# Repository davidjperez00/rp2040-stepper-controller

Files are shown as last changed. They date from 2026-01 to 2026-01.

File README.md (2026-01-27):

# rp2040-stepper-controller
This project utilizes the RP2040 microcontroller and A4988 motor drivers on a custom PCB to control NEMA-17 stepper motors. This PCB is equipped with four A4988 providing the ability to drive multiple motors from a single microntroller. Headers pins provide the ability of micro-stepping for each motor. The micro-USB allows for easy flashing from a host machine. The 32MB of external flash memory provide the ability to flash large programs.

## Demo (Click Thumbnail to see Youtube video)
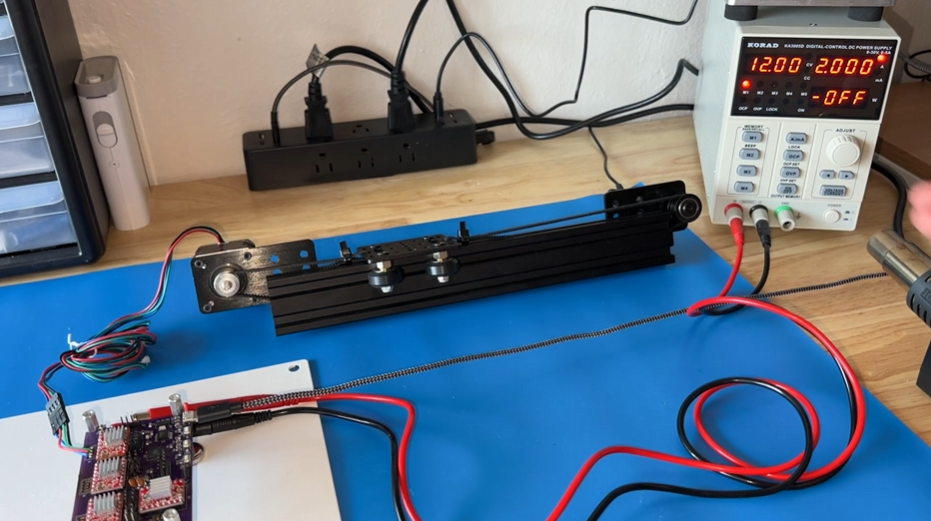
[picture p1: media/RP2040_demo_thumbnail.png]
Video Demo Thumbnail (https://www.youtube.com/watch?v=CGf28lo1xpw)


## PCB Snapshots
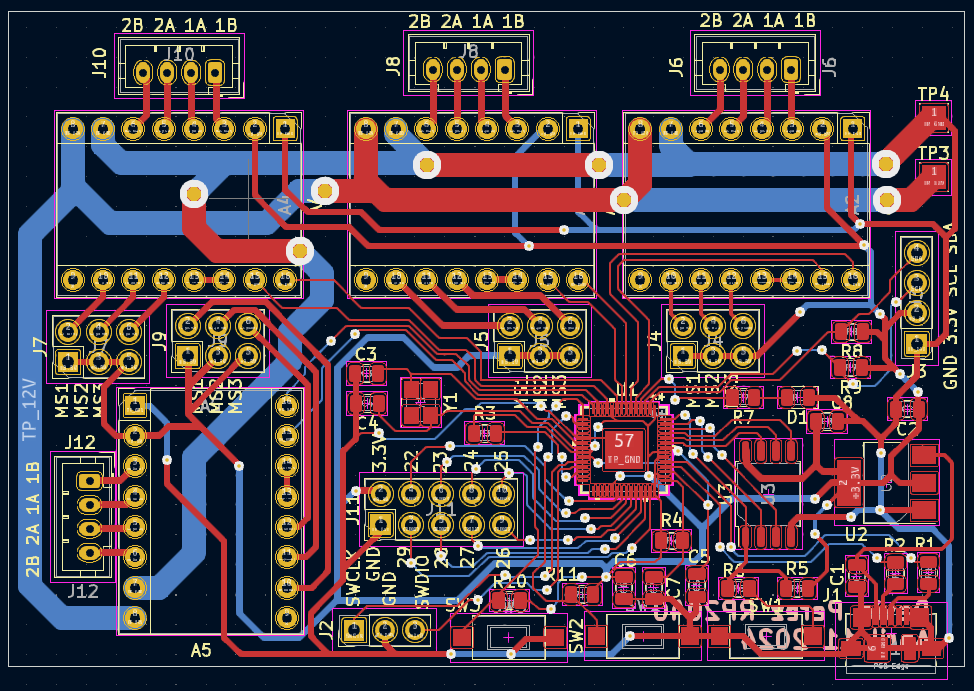
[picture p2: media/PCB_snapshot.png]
PCB snapshot


## Schematic Snapshots
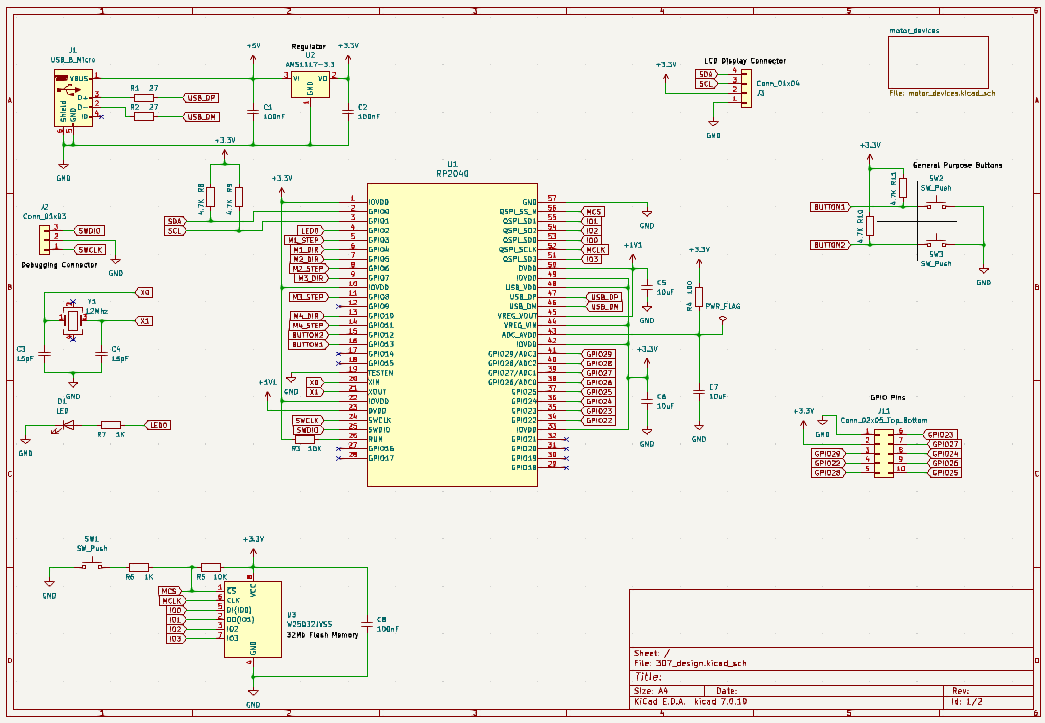
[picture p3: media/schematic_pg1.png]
Schematic Page 1

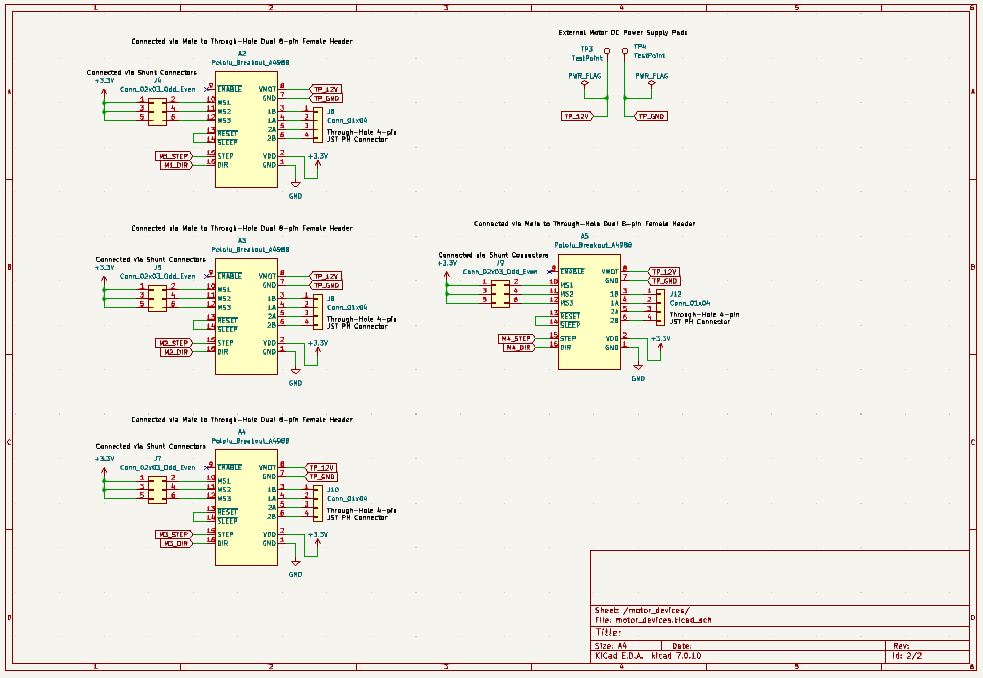
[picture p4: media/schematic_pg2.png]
Schematic Page 2


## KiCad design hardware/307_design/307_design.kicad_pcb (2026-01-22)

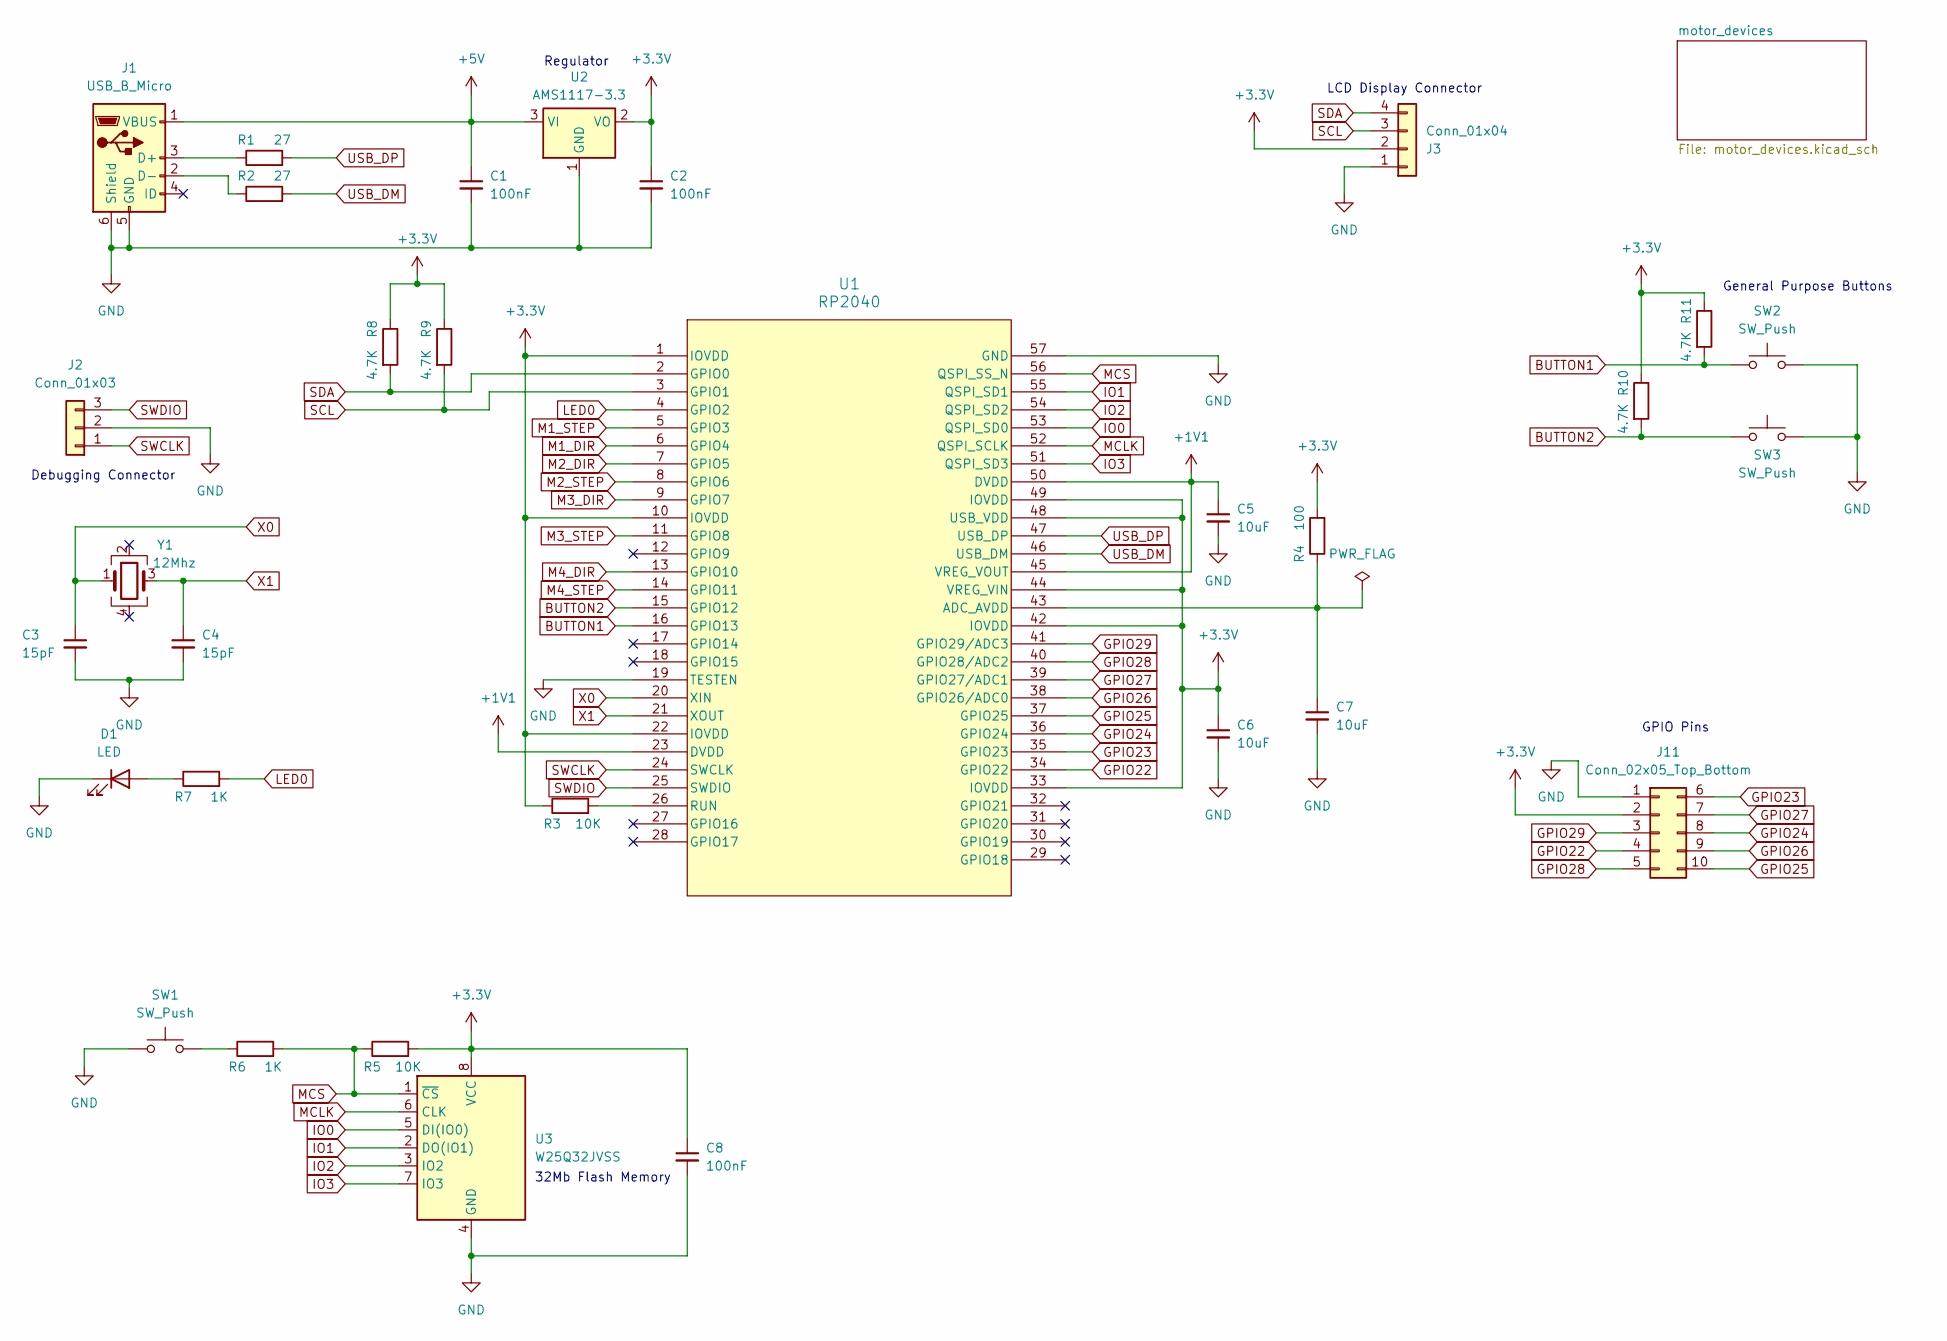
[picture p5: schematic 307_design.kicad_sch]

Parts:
C1, C2, C8: 100nF; C_0805_2012Metric
C3, C4: 15pF; C_0805_2012Metric
C5, C6, C7: 10uF; C_0805_2012Metric
D1: LED; LED_0805_2012Metric
J1: USB_B_Micro; USB_Micro-B_Molex_47346-0001
J2: Conn_01x03; PinHeader_1x03_P2.54mm_Vertical
J3: Conn_01x04; PinHeader_1x04_P2.54mm_Vertical
J11: Conn_02x05_Top_Bottom; PinHeader_2x05_P2.54mm_Vertical
R1, R2: 27; R_0805_2012Metric
R3, R5: 10K; R_0805_2012Metric
R4: 100; R_0805_2012Metric
R6, R7: 1K; R_0805_2012Metric
R8, R9, R10, R11: 4.7K; R_0805_2012Metric
SW1, SW2, SW3: SW_Push; SW_SPST_CK_RS282G05A3
U1: RP2040; IC57_RP2040
U2: AMS1117-3.3; SOT-223-3_TabPin2
U3: W25Q32JVSS; SOIC-8_5.23x5.23mm_P1.27mm
Y1: 12Mhz; Crystal_SMD_SeikoEpson_FA238-4Pin_3.2x2.5mm

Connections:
+1V1: C5.1, U1.23 (DVDD), U1.45 (VREG_VOUT), U1.50 (DVDD)
+3.3V: C2.1, C6.1, C8.1, J3.2, J11.2, R3.1, R4.2, R5.2, R8.1, R9.1, R10.1, R11.1, U1.1 (IOVDD), U1.10 (IOVDD), U1.22 (IOVDD), U1.33 (IOVDD), U1.42 (IOVDD), U1.44 (VREG_VIN), U1.48 (USB_VDD), U1.49 (IOVDD), U2.2 (VO), U3.8 (VCC); also elsewhere on the board
+5V: C1.1, J1.1 (VBUS), U2.3 (VI)
BUTTON1: R11.2, SW2.1, U1.16 (GPIO13)
BUTTON2: R10.2, SW3.1, U1.15 (GPIO12)
GPIO22: J11.4, U1.34 (GPIO22)
GPIO23: J11.6, U1.35 (GPIO23)
GPIO24: J11.8, U1.36 (GPIO24)
GPIO25: J11.10, U1.37 (GPIO25)
GPIO26: J11.9, U1.38 (GPIO26/ADC0)
GPIO27: J11.7, U1.39 (GPIO27/ADC1)
GPIO28: J11.5, U1.40 (GPIO28/ADC2)
GPIO29: J11.3, U1.41 (GPIO29/ADC3)
IO0: U1.53 (QSPI_SD0), U3.5 (DI(IO0))
IO1: U1.55 (QSPI_SD1), U3.2 (DO(IO1))
IO2: U1.54 (QSPI_SD2), U3.3 (IO2)
IO3: U1.51 (QSPI_SD3), U3.7 (IO3)
LED0: R7.2, U1.4 (GPIO2)
M1_DIR: U1.6 (GPIO4); also elsewhere on the board
M1_STEP: U1.5 (GPIO3); also elsewhere on the board
M2_DIR: U1.7 (GPIO5); also elsewhere on the board
M2_STEP: U1.8 (GPIO6); also elsewhere on the board
M3_DIR: U1.9 (GPIO7); also elsewhere on the board
M3_STEP: U1.11 (GPIO8); also elsewhere on the board
M4_DIR: U1.13 (GPIO10); also elsewhere on the board
M4_STEP: U1.14 (GPIO11); also elsewhere on the board
MCLK: U1.52 (QSPI_SCLK), U3.6 (CLK)
MCS: R5.1, R6.2, U1.56 (QSPI_SS_N), U3.1 (~CS)
unnamed: D1.2 (A), R7.1
unnamed: J1.3 (D+), R1.1
unnamed: J1.2 (D-), R2.1
unnamed: R6.1, SW1.2
unnamed: C7.1, R4.1, U1.43 (ADC_AVDD)
unnamed: R3.2, U1.26 (RUN)
SCL: J3.3, R9.2, U1.3 (GPIO1)
SDA: J3.4, R8.2, U1.2 (GPIO0)
SWCLK: J2.1, U1.24 (SWCLK)
SWDIO: J2.3, U1.25 (SWDIO)
USB_DM: R2.2, U1.46 (USB_DM)
USB_DP: R1.2, U1.47 (USB_DP)
X0: C3.1, U1.20 (XIN), Y1.1
X1: C4.1, U1.21 (XOUT), Y1.3

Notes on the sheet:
General Purpose Buttons
Debugging Connector
GPIO Pins
LCD Display Connector
Regulator
32Mb Flash Memory

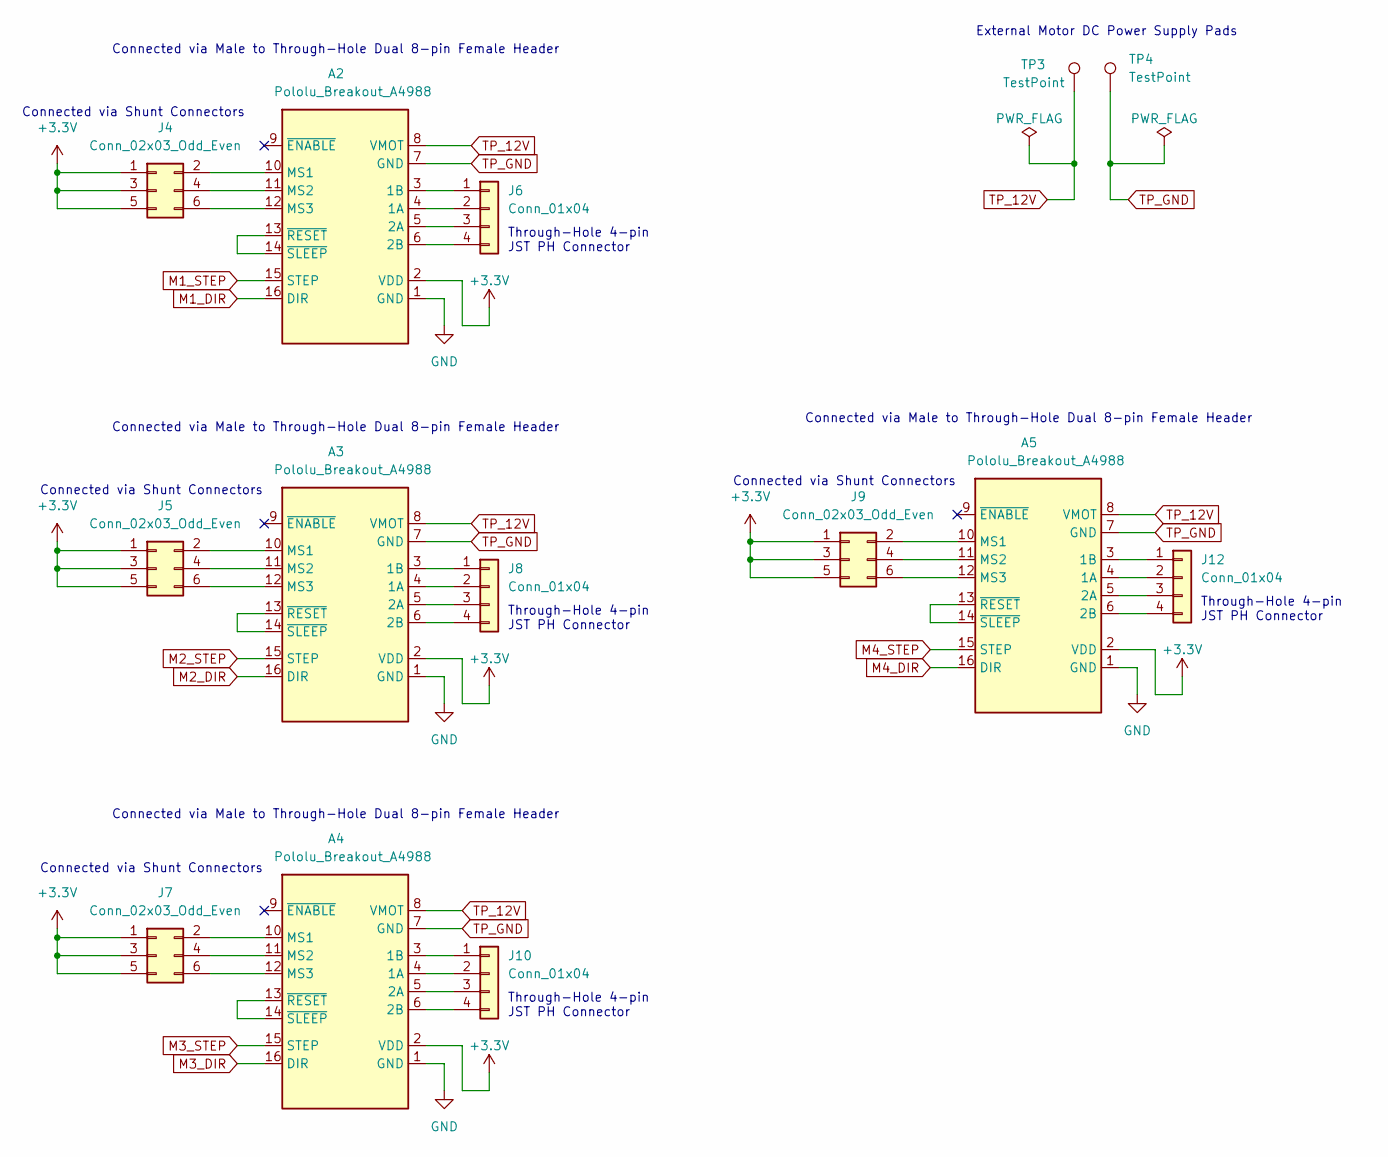
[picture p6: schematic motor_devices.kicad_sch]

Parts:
A2, A3, A4, A5: Pololu_Breakout_A4988; Pololu_Breakout-16_15.2x20.3mm
J4, J5, J7, J9: Conn_02x03_Odd_Even; PinHeader_2x03_P2.54mm_Vertical
J6, J8, J10, J12: Conn_01x04; JST_PH_B4B-PH-K_1x04_P2.00mm_Vertical
TP3, TP4: TestPoint; TestPoint_Pad_2.0x2.0mm

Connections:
+3.3V: A2.2 (VDD), A3.2 (VDD), A4.2 (VDD), A5.2 (VDD), J4.1, J4.3, J4.5, J5.1, J5.3, J5.5, J7.1, J7.3, J7.5, J9.1, J9.3, J9.5; also elsewhere on the board
M1_DIR: A2.16 (DIR); also elsewhere on the board
M1_STEP: A2.15 (STEP); also elsewhere on the board
M2_DIR: A3.16 (DIR); also elsewhere on the board
M2_STEP: A3.15 (STEP); also elsewhere on the board
M3_DIR: A4.16 (DIR); also elsewhere on the board
M3_STEP: A4.15 (STEP); also elsewhere on the board
M4_DIR: A5.16 (DIR); also elsewhere on the board
M4_STEP: A5.15 (STEP); also elsewhere on the board
unnamed: A2.4 (1A), J6.2
unnamed: A2.3 (1B), J6.1
unnamed: A2.5 (2A), J6.3
unnamed: A2.6 (2B), J6.4
unnamed: A2.10 (MS1), J4.2
unnamed: A2.11 (MS2), J4.4
unnamed: A2.12 (MS3), J4.6
unnamed: A2.13 (~RESET), A2.14 (~SLEEP)
unnamed: A3.4 (1A), J8.2
unnamed: A3.3 (1B), J8.1
unnamed: A3.5 (2A), J8.3
unnamed: A3.6 (2B), J8.4
unnamed: A3.10 (MS1), J5.2
unnamed: A3.11 (MS2), J5.4
unnamed: A3.12 (MS3), J5.6
unnamed: A3.13 (~RESET), A3.14 (~SLEEP)
unnamed: A4.4 (1A), J10.2
unnamed: A4.3 (1B), J10.1
unnamed: A4.5 (2A), J10.3
unnamed: A4.6 (2B), J10.4
unnamed: A4.10 (MS1), J7.2
unnamed: A4.11 (MS2), J7.4
unnamed: A4.12 (MS3), J7.6
unnamed: A4.13 (~RESET), A4.14 (~SLEEP)
unnamed: A5.4 (1A), J12.2
unnamed: A5.3 (1B), J12.1
unnamed: A5.5 (2A), J12.3
unnamed: A5.6 (2B), J12.4
unnamed: A5.10 (MS1), J9.2
unnamed: A5.11 (MS2), J9.4
unnamed: A5.12 (MS3), J9.6
unnamed: A5.13 (~RESET), A5.14 (~SLEEP)
TP_12V: A2.8 (VMOT), A3.8 (VMOT), A4.8 (VMOT), A5.8 (VMOT), TP3.1

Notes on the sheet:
Connected via Shunt Connectors
External Motor DC Power Supply Pads
Connected via Male to Through-Hole Dual 8-pin Female Header
Through-Hole 4-pin JST PH Connector

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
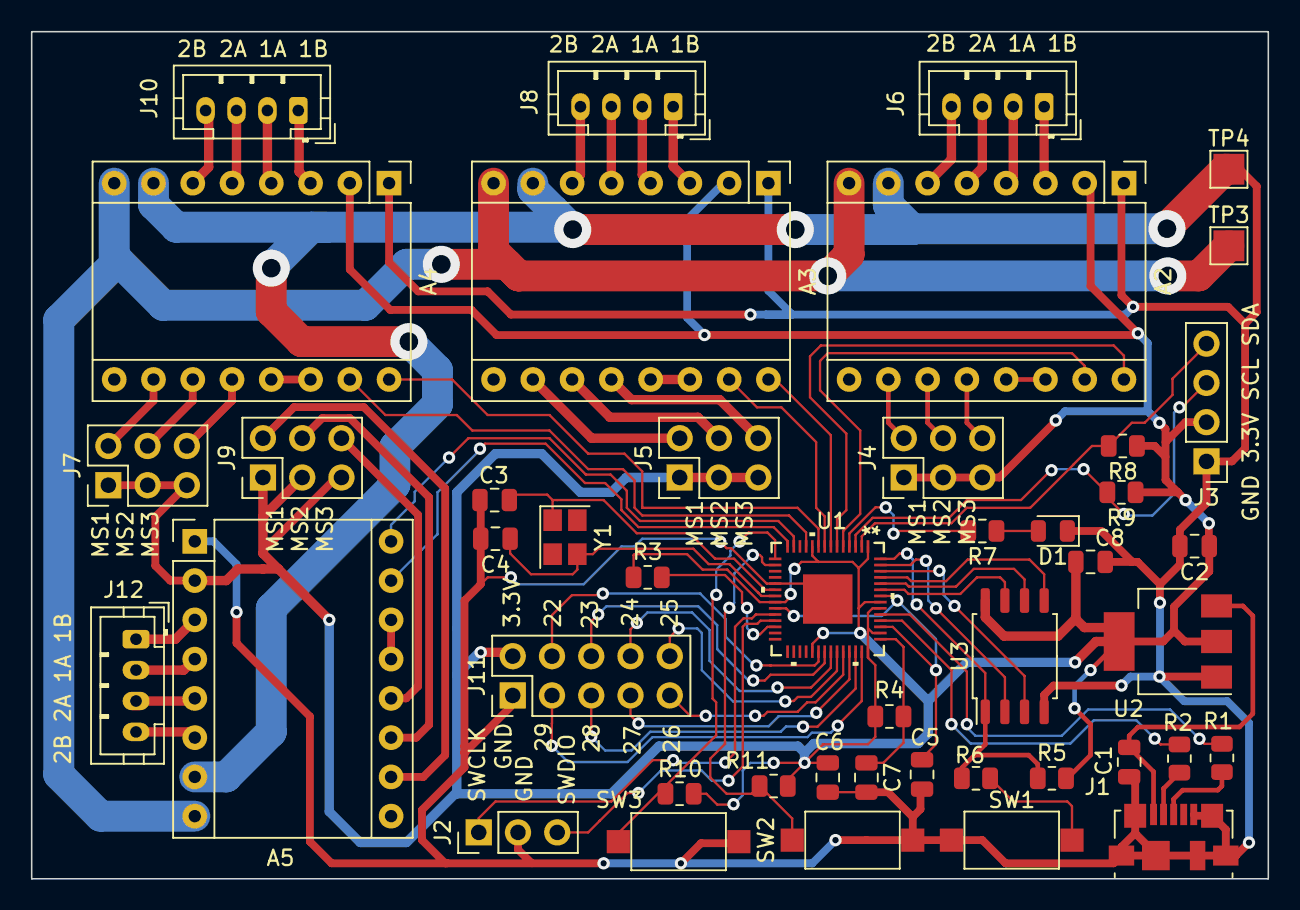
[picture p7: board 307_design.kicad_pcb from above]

Board: 2 copper layers, 80.0 x 54.8 mm, 45 parts (0 on the bottom side), 76 nets.

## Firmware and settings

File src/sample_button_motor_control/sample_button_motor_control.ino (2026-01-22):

#define STEP_PIN 3
#define DIR_PIN  4
#define ON_BOARD_LED_PIN 2
#define SWITCH_2_PIN 13
#define SWITCH_3_PIN 12


void setup() {
  delay(2000); // ms

  Serial.begin(9600);
  while (!Serial); // wait for USB to be ready

  pinMode(STEP_PIN, OUTPUT);
  pinMode(DIR_PIN, OUTPUT);
  pinMode(ON_BOARD_LED_PIN, OUTPUT);
  pinMode(SWITCH_2_PIN, INPUT);
  pinMode(SWITCH_3_PIN, INPUT);

    // Blink LED to indicate program started!
  for (int i = 0; i < 3; i++) {
    Serial.println("starting blinking");
    digitalWrite(ON_BOARD_LED_PIN, HIGH);
    delay(200); // ms
    digitalWrite(ON_BOARD_LED_PIN, LOW);
    delay(200); // ms
  }
  
}

void stepOnce() {
  digitalWrite(STEP_PIN, HIGH);
  delayMicroseconds(50);   // pulse width
  digitalWrite(STEP_PIN, LOW);
  delayMicroseconds(50);
}

void stepMultiple(bool rotate_clockwise, uint16_t num_turns) {

  if (rotate_clockwise){
    digitalWrite(DIR_PIN, HIGH);  // set direction
    Serial.println("Step direction clockwise rotation");

  } else {
    digitalWrite(DIR_PIN, LOW);  // set direction
    Serial.println("Step direction counter-clockwise rotation");

  }

  Serial.printf("Rotating %u steps \r\n", num_turns);
  
  for (int i = 0; i < num_turns; i++) {
    stepOnce();
  }
}


static uint32_t lastTime[32] = {0};
static bool lastStable[32] = {HIGH};

bool debouncePressed(uint8_t pin, uint32_t debounce_ms = 50) {
  bool reading = digitalRead(pin);

  if (reading != lastStable[pin]) {
    lastTime[pin] = millis();
  }

  if ((millis() - lastTime[pin]) > debounce_ms) {

    if (reading != lastStable[pin]){
      lastStable[pin] = reading;
    }
    
    if (reading == LOW) {
      return true;
    }
  }

  return false;
}


void loop() {
  // Turn the servo clockwise
  if (debouncePressed(SWITCH_2_PIN)){
    stepMultiple(true, 1000);
  }

  // Turn the servo counter-clockwise
  if (debouncePressed(SWITCH_3_PIN)){
    stepMultiple(false, 1000);
  }
}

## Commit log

2026-01-20 Upload previous hardware implementation
    [307_design.kicad_pcb, 307_design.kicad_sch, motor_devices.kicad_sch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]
2026-01-22 update traces and add sample program
    [307_design.kicad_pcb]
